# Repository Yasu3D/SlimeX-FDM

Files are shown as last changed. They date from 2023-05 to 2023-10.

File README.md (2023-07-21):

### !! This case was designed for specific parts, check [Guides](/README.md#-guides) for more info. !!
 
 It *may* fit other parts, but those setups are neither tested nor supported.

# 🦈 SlimeX-FDM
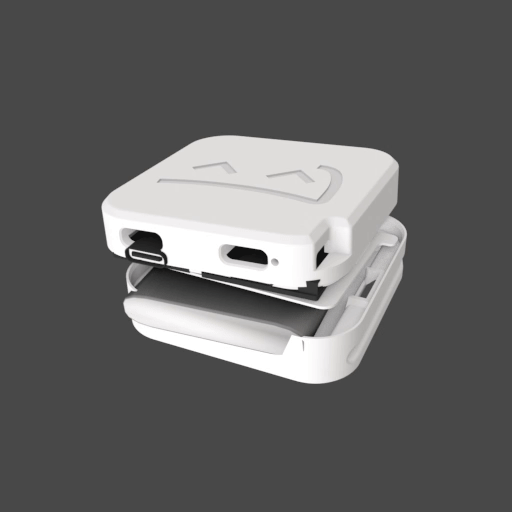
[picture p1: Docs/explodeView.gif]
woa cool animation

> woa cool animation

An easy to print, clean and very compact case design for SlimeVR.
Based on GniloAloe's SlimeX case, which is based on StonX.

Gniloe's design was intended for SLA printers. SlimeX-FDM is an adjusted version designed to be easier to print on FDM machines.

# ⚠️ Battery Safety Warning
- ***ALWAYS** separate the battery from the circuit boards to protect the battery from being poked by solder joints. Use a piece of craft foam or the provided 3d-printable battery-protector plastic card.*

- *Don't use V1 if you have battery tolerance issues!*

- *This case design is a **very** tight fit and may put a considerable amount of pressure on the battery if assembled incorrectly.*

- *Always ensure that your battery is safe and not a bomb please. I do not want to be held accountable for exploding trackers.*

# 📄 Changelog
| Version | Changes |
| - | - |
| V1 | Base Design |
| V2 | More space for battery, slightly larger I2C port |
| V3 | Complete remodel in Fusion360, .step file now available |
| V3.1 | Improved the clips, cases should stay together better now. |
| V3.2 | Fixed switch tolerances and made version text more readable. |
| V3.3 | Fixed case proportions on top and bottom, changed walls internally to get rid of gaps, changed i2c area to not destroy ports on insertion of wemos into slot, moved wemos pegs up for clearance, Inbuilt supports for top and buttom minus strap area, added indicator versions. |

# 📝 Guides
Always refer to the [SlimeVR Docs](https://docs.slimevr.dev/index.html) for the most up-to-date information. If you have any questions, ask in the [SlimeVR Discord](https://discord.gg/SlimeVR), DM me on Discord [Yasu#4645] or send me an [E-Mail](mailto:contact@yasu3d.art)

## Parts
SlimeX-FDM was designed around these parts. Resistors and Diodes obviously fit as well.
 - Wemos D1 Mini V4 Wifi Board // [Aliexpress](https://www.aliexpress.com/item/1005004605967379.html)
 - TP4056 USB-C Charger Board// [Aliexpress](https://www.aliexpress.com/item/1005004427739715.html)
 - SS22F32 Switch // [Aliexpress](https://www.aliexpress.com/item/1005003660190950.html)
 - BMI160 IMUs // [Aliexpress](https://www.aliexpress.com/item/4000084874141.html)
 - 804040 Li-Po Batteries // [Aliexpress](https://www.aliexpress.com/item/4000036291424.html)
 - 28AWG stranded silicone wire
 - [JST 1mm 4-pin / JST SH 4-pin connectors](https://jst.de/product-family/show/65/sh) for auxillary trackers // [Aliexpress](https://www.aliexpress.com/item/1005004350939786.html)

> please note that the Aliexpress pages are only for reference. It's recommended to look for other offers yourself.

> if any page is unavailable, the part name should be enough to find them.

> 1mm JST connector cables rarely come in lengths longer than 15cm. The linked page offers up to 30cm.

## 3D Printing
### Config
***TL;DR** 0.4mm nozzle, 0.15mm layers, 15% gyroid infill, arachne.*
***Can also print at .2 layer height, .2 initial layer height.*

Full config (that's been successful for me) can be found [here.](/Docs/SLICERCONFIG.md)

### Orientation/Arrangement
All STL files are exported in their correct orientation. The hollow inside of each case piece should point up:
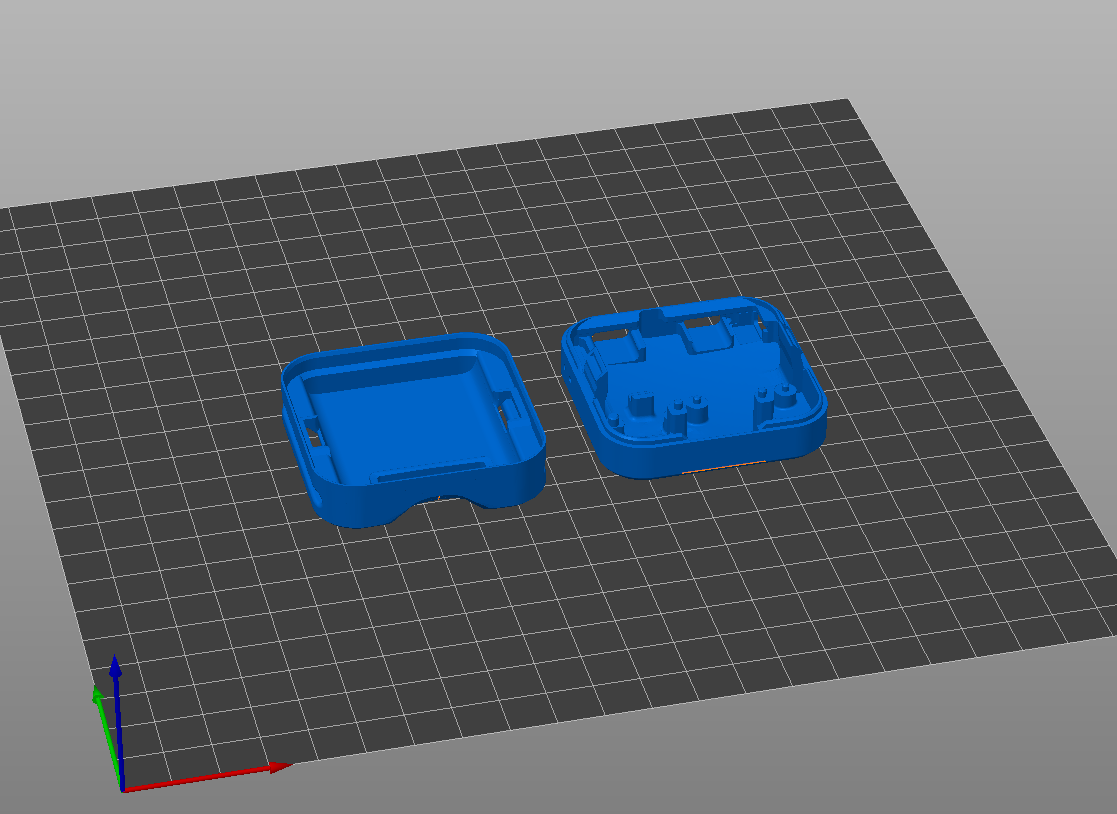
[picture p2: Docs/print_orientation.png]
print orientation

> This allows the case to be printed with minimal supports.

### Supports
If possible, use support-painting and organic supports with a slicer like PrusaSlicer 2.6.0.
This makes support material less wasteful and makes removing supports an absolute breeze.

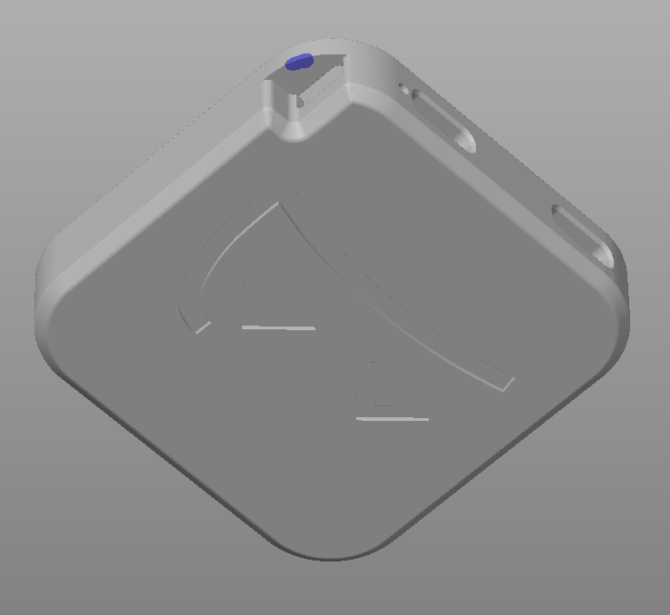
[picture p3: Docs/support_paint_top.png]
supports1

> supports under the I2C interface for auxillary trackers

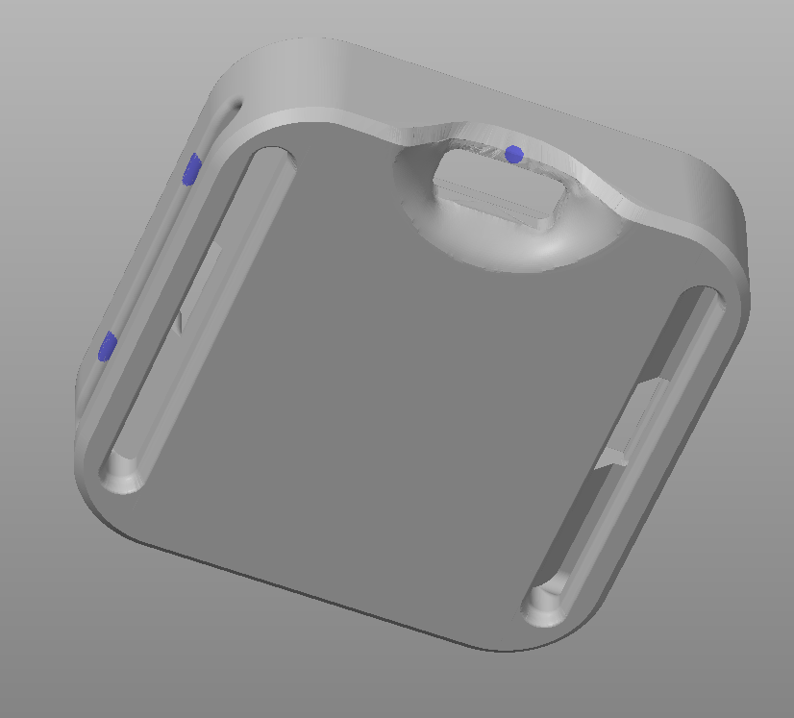
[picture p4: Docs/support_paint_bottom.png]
supports2

> supports for bridges around strap slots + support for bridge around switch.

> support painting on bottom shell is symmetrical.

## Soldering
//TBD, check smeltieVR's guide "Soldering for dummies" to learn the basics.

## Assembly
### Closing an empty case
- Line up pegs with switch slot
- Hook one clip into a slot
- Push halves together, slowly increasing pressure until it snaps shut.

its as shrimple as that

### Assembling a full tracker (refer to animation for visual guide)
**Battery:** (bottom case)
- Place battery in bottom case. May require a little pushing to move the circuit board at the top of the battery. That's fine.
- Route the battery cable in a way that it pokes out on the right side of the switch slot.

**Boards:** (top case)
- Place the BMI160 in the top right corner, make sure that it is laying flat or as flat as possible. Bend wiring if necessary.
- Push TP4056 and Wemos D1 Mini into the bottom half of the case. They're a very tight fit and assembly might be tricky because of the clips, wiring and pegs. Patience and some pressure is key to get them in their spot.
- Make sure the TP4056 lies flat and that the USB-C port is almost flush with the port on the case. If necessary, bend some wiring.
- Make sure the D1 Mini's I2C interface lines up with the port on the case. (the small cutout on one of the corners)
> - The D1 Mini's USB-C port does not poke out as much as the TP4056. That's normal, you'll still be able to access it.
> - The D1 Mini's I2C interface should line up, even if the tracker won't be used with an auxillary tracker. That's because the USB-C port may be too far in to properly access and because the pegs the D1 Mini sits on may not align.
> - It sometimes takes a considerable amount of force to get the D1 Mini in place. It feels a little scary, but it's normal.

**Switch:**
- Place the switch on the pegs, not in the slot. This is to ensure alignment when closing the case.
- If your wiring is too long the switch may become temperamental and will jump off the pegs. Press it down and optionally tape it to show it who's boss and put it in it's place.

**Closing:**
- Same process as an empty case, but this time you have to do it with a bunch of components in the way.
- Make sure nothing's poking the battery
- Make sure nothing's in the way of the switch and clips.
- Conglaturations! You did it :3

[May your trackers be many and your drifters few.](https://www.youtube.com/watch?v=CgHS1fa69aU)

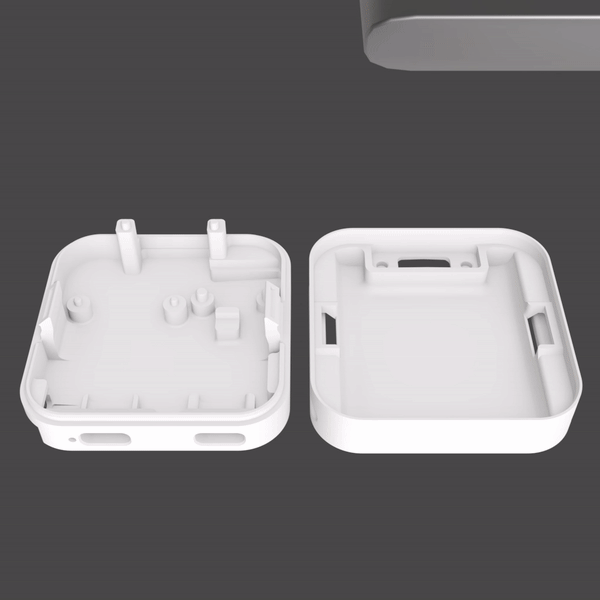
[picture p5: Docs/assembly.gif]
woo other cool animation


## Disassembly
If you need to troubleshoot or maintain your trackers, they're easily opened with the flat end of tweezers or a butter knife. Be slow to ensure you don't break anything.
- Hold case gentle like hamster
- Gently push against one of the clips inside the strap slots
- Apply a little force upwards with your fingers until case pops free.
 
Mind the cables and battery. You can carefully open the tracker like a book along the top edge (where the switch is).

disassembly IRL

## Durability
Standard PLA(+) is recommended. ***Don't use silk PLA.***
If your filament is brittle, the clips *may* break. 

I durability-tested with silk and non-silk PLA+ and the clips on silk cases snapped with minor force applied. I couldn't even break a non-silk clip so far. (I've tried about 5 times with all my strength. It just doesn't want to break.)

If you repeatedly open and close a case (20+ times), you ***will*** shave off the small hooks that make the clips work properly. Once worn down, the case will still stay together but can easily be opened by pulling the two halves apart. This may be fixed in a design revision, but it's hard to find a balance between ease of use and durability for the clips. Just press against the clips and open them slowly, then you'll be ok.

I've also stood on top of a case (~85kg) and it didn't even buckle much lol. You'll be fine laying on one if your bed isn't made of concrete.

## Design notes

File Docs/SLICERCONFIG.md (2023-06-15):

## [Back to README.md](/)

# 🖨️ My printer
- Stock Voron 2.4r2 350mm (current)
  - E3D v6 w/ 0.4mm nozzle

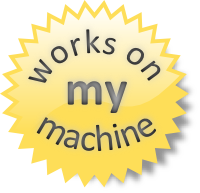
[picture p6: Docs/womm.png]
works on my machine


# ⚙️ My config - using Prusaslicer 2.6.0-rc1

## Print
Anything not mentioned is either irrelevant or probably standard.
These settings are for my Voron 2.4

### Layers and Perimeters
| Parameter | Value |
| - | - |
| Layer height | 0.15mm |
| First layer height | 0.2mm |
| Perimeters | 3 |
| Solid top layers | 6 |
| Solid bottom layers | 5 |
| Thick bridges | ☑ |
| Detect bridging perimeters | ☑ |
| Fill gaps | ☑ |
| Perimeter generator | Arachne |

### Infill, Skirts and Supports

| Parameter | Value |
| - | - |
| Fill density | 15% |
| Fill pattern | Gyroid or Cubic |
|  |  |
| Skirt loops | 3 (maybe overkill and irrelevant to the print) |
|  |  |
| Support style | Organic |
| Top contact Z  | 0.15mm |
| Bottom contact Z | 0.15mm |
| Interface layers | 1 |

### Speeds
This is very printer-dependent. Don't blindly copy this.

| Parameter | Value |
| - | - |
| Perimeters | 100mm/s |
| Small perimeters | 40mm/s |
| External perimeters | 40mm/s |
| Infill | 125mm/s |
| Solid infill | 120mm/s |
| Top solid infill | 50mm/s |
| Supports | 90mm/s |
| Support interface | 70mm/s |
| Bridges | 60mm/s |
| Gap fill | 40mm/s |
| First layer speed | 30mm/s |

## Filament

- Sunlu Marble PLA+

| Parameter | Value |
| - | - |
| Diameter | 1.75mm |
| Extrusion multiplier | 1 |
| Nozzle temp. | 205°C |
| Bed temp. | 60°C |

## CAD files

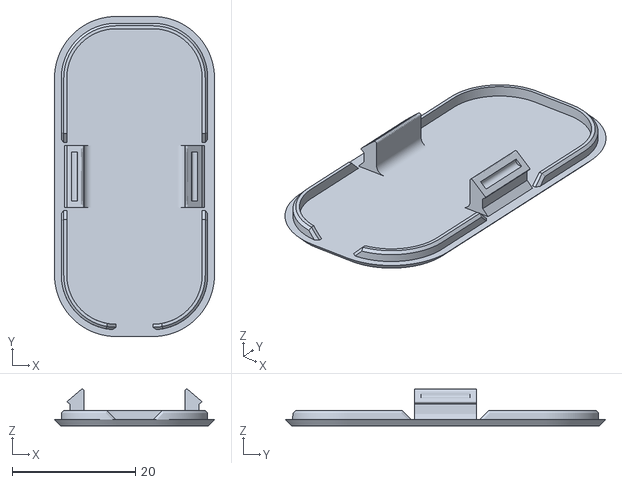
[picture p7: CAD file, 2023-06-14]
Case Files/AuxCases/V3.1/V3.1_SlimeX-FDM_Aux_Top.stl
26.0 x 52.0 x 5.97

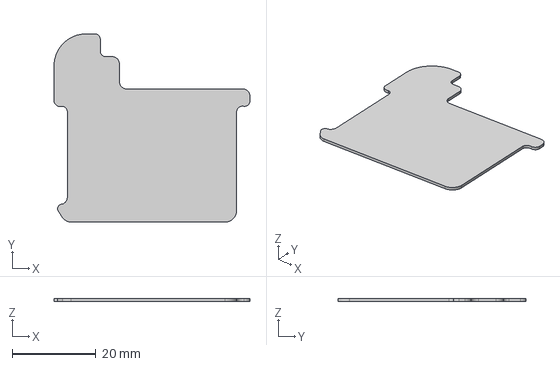
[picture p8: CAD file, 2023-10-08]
Case Files/MainCases/Battery Protector/Battery Protector.step
46.9 x 45.0 x 0.7 mm

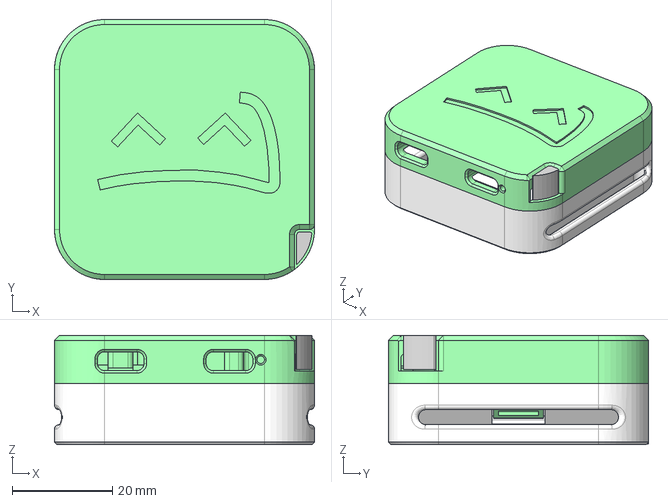
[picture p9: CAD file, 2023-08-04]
Case Files/MainCases/V3.3/Cad Files/V3.3_SlimeX-FDM.step
52.0 x 52.0 x 21.8 mm
SlimeX Top
SlimeX Bottom

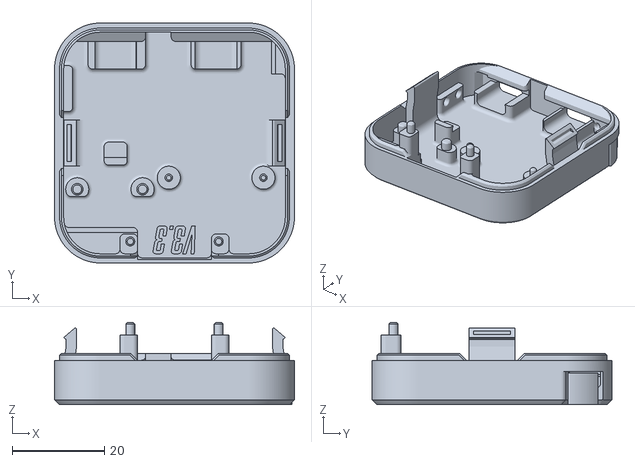
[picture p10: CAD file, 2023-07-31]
Case Files/MainCases/V3.3/Standard/SlimeX Top.stl
52.0 x 52.0 x 17.8

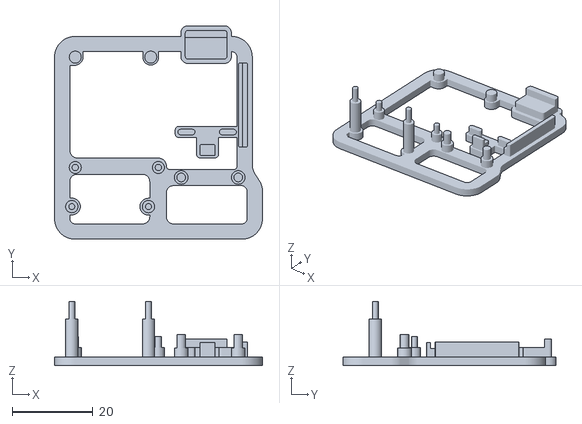
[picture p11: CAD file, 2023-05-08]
Case Files/SlimeX_SolderGuide_V3.stl
51.6 x 53.0 x 15.9

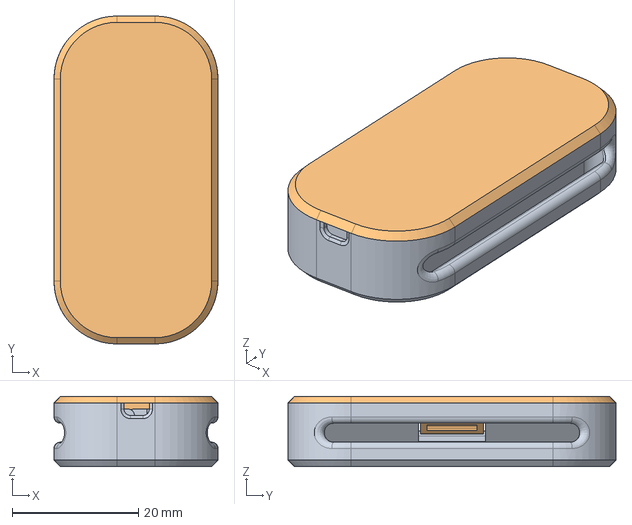
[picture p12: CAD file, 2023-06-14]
Case Files/AuxCases/V3.1/V3.1_SlimeX-FDM_Aux.step
26.0 x 52.0 x 11.1 mm
SlimeX Auxillary Bottom
SlimeX Aux Top

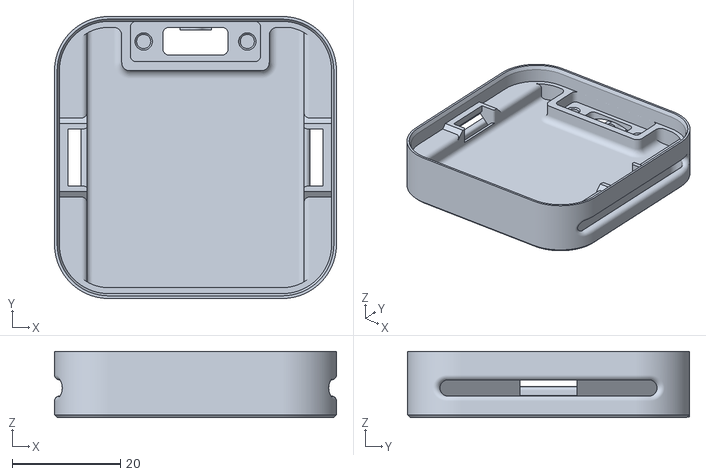
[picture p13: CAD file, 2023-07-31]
Case Files/MainCases/V3.3/Standard/SlimeX Bottom.stl
52.0 x 52.0 x 12.2

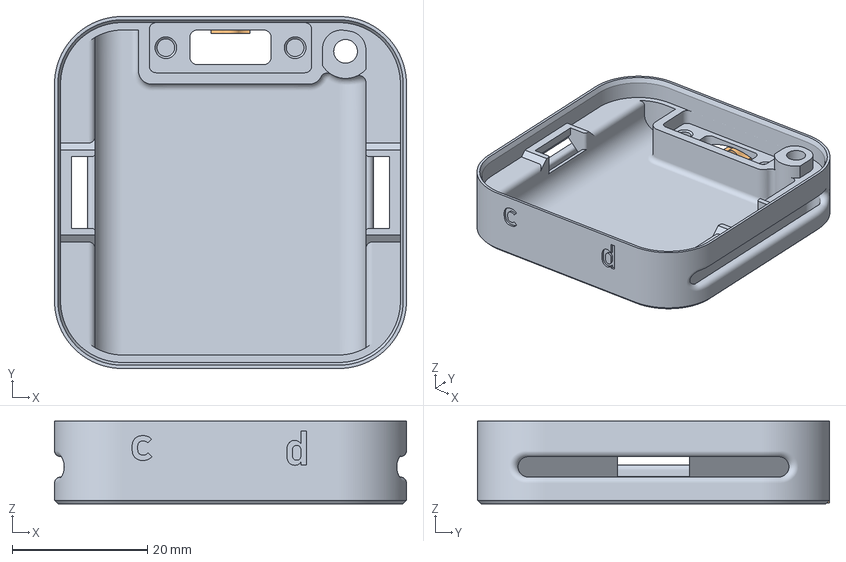
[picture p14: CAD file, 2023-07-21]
Case Files/MainCases/V3.3/With indicators/SlimeX Bottom with indicators.3mf
52.0 x 52.0 x 12.2 mm
Support

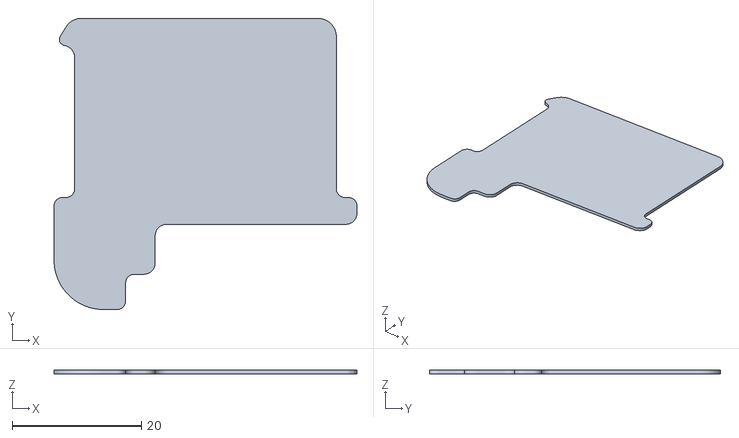
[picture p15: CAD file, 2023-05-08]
Case Files/SlimeX-FDM_BatteryProtector.stl
46.9 x 45.0 x 0.577

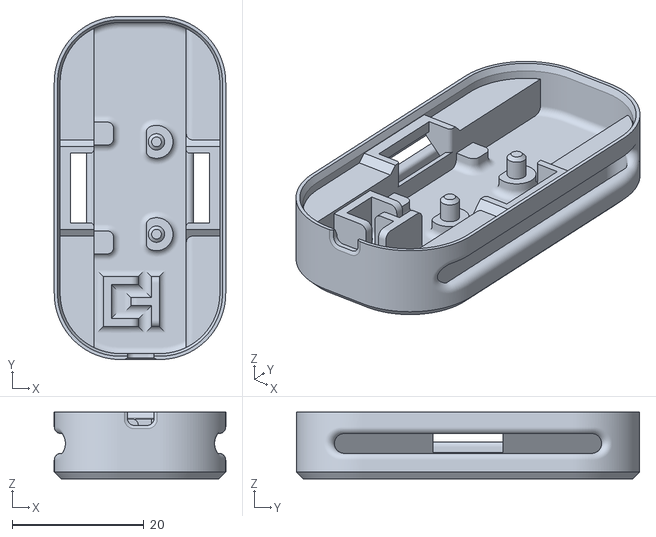
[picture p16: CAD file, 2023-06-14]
Case Files/AuxCases/V3.1/V3.1_SlimeX-FDM_Aux_Bottom.stl
26.0 x 52.0 x 10.1

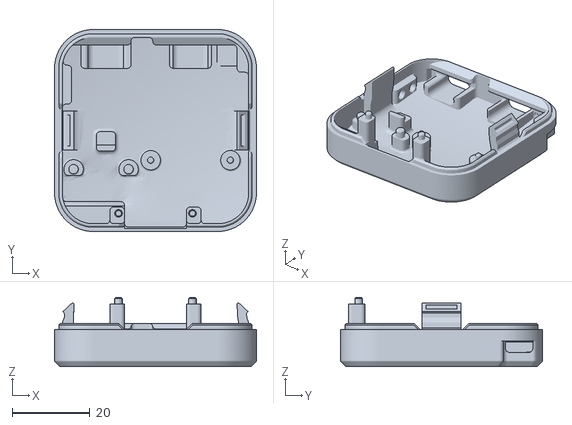
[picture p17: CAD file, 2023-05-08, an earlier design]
Case Files/MainCases/V1.0/SlimeX-FDM_Top.stl
52.0 x 52.0 x 17.8

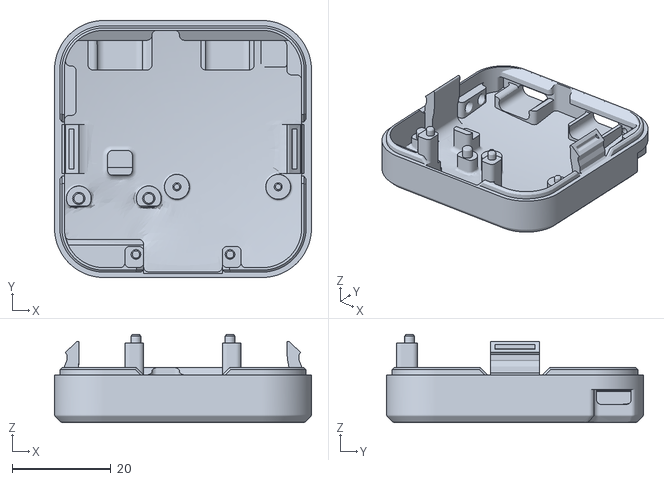
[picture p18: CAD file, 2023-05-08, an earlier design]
Case Files/MainCases/V1.0/SlimeX-FDM_Top_NoLogo.stl
52.0 x 52.0 x 17.8

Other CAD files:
Case Files/MainCases/V3.3/With indicators/SlimeX Top with indicators.3mf
Case Files/MainCases/V2.0/SlimeX-FDM_Bottom_V2.stl
Case Files/MainCases/V3.0/V3.0_SlimeX-FDM_Top_Logo.stl
Case Files/MainCases/V3.1/V3.1_SlimeX-FDM_Top_Logo.stl
Case Files/MainCases/V3.2/V3.2_SlimeX-FDM.step
Case Files/MainCases/V2.0/SlimeX-FDM_Top_V2.stl
Case Files/MainCases/V1.0/SlimeX-FDM_Bottom.stl
Case Files/MainCases/V2.0/SlimeX-FDM_Top_NoLogo_V2.stl
Case Files/MainCases/V3.0/V3.0_SlimeX-FDM.step
Case Files/MainCases/V3.0/V3.0_SlimeX-FDM_Bottom.stl
Case Files/MainCases/V3.0/V3.0_SlimeX-FDM_Top_NoLogo.stl
Case Files/MainCases/V3.1/V3.1_SlimeX-FDM.step
Case Files/MainCases/V3.1/V3.1_SlimeX-FDM_Bottom.stl
Case Files/MainCases/V3.1/V3.1_SlimeX-FDM_Top_NoLogo.stl
Case Files/MainCases/V3.2/V3.2_SlimeX-Bottom.stl
Case Files/MainCases/V3.2/V3.2_SlimeX-FDM_Top_Logo.stl
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

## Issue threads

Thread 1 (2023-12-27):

What is the license used?

Christmaswreath, 2023-12-27:

Yasu3D, 2023-12-27:
I haven't put proper thought into that / bothered writing my own license.

I suppose the best fitting license would be CC-BY-NC-SA.

TL;DR of what I'm expecting:
- Provide credit when sharing (link to this repository is fine)
- Only for Non-Commercial use, **unless you have my explicit permission**.
  - You cannot sell the 3d *model*.
  - You cannot sell 3d *prints*.
  - You cannot sell trackers made with this case.
- Any derivative works must follow this license as well.

It's also encouraged to contribute directly to this project and not create "new" versions of it. If you improve the design and want to share it, open a pull request.

Closed 2023-12-27.

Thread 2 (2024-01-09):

Compatibility with the community-made BMI270 and LSM6DSV gyros

barretgoat, 2024-01-09:
I want to preface this write-up by saying that it is not as much of an issue as it is an opportunity for improvement of the design.

A community member in the SlimeVR Discord server has started offering breakout boards carrying improved IMUs, the BMI270 and the LSM6DSV, both showing vastly improved performance over the BMI160 yet having exactly the same dimensions and overall footprint.

The only difference is that to simplify the trace routing, the author opted to remove the mounting holes, which renders SlimeX the only case that is currently unable to fit the new gyros on account of actually making use of the mounting holes in BMI160 boards.

The current cases still work if one were to break off the thin part of the mounting posts with pliers and then secure the IMU with some hotglue, but I suspect that the case file could just as easily be reworked to accomodate the community IMUs without breaking the compatibility with the BMI160.

The simplest way I can see is removing the part of the posts which actually goes in the hole on the board and ensuring that the support for the charging board is close enough to the IMU that it is held in place by friction alone, though I suspect there might be a smarter way to go about it.

Also, linking the Discord thread with the discussion of the new IMUs: https://discord.com/channels/817184208525983775/1176860516140978308

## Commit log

2023-05-08 push v1 case
    [SlimeX-FDM_BatteryProtector.stl, SlimeX-FDM_Bottom.stl, SlimeX-FDM_Top.stl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]
2023-05-21 uploaded new V2 case and reorganized things
    [SlimeX-FDM_BatteryProtector.stl, SlimeX-FDM_Bottom_V2.stl, SlimeX-FDM_Top_NoLogo_V2.stl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]
2023-05-24 fix scaling on V2 STLs
    [SlimeX-FDM_Bottom_V2.stl, SlimeX-FDM_Top_NoLogo_V2.stl, SlimeX-FDM_Top_V2.stl]
2023-05-25 restructuring and v3.0 release
    [SlimeX-FDM_BatteryProtector.stl, SlimeX-FDM_Bottom.stl, SlimeX-FDM_Bottom_V2.stl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]
2023-05-25 flipped cases
    [V3.0_SlimeX-FDM_Top_Logo.stl, V3.0_SlimeX-FDM_Top_NoLogo.stl]
2023-05-25 update to v3.1 for better clips
    [V3.1_SlimeX-FDM.step, V3.1_SlimeX-FDM_Bottom.stl, V3.1_SlimeX-FDM_Top_Logo.stl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]
2023-05-25 fix dumb mistake thats not worth a version number
    [V3.1_SlimeX-FDM_Top_Logo.stl, V3.1_SlimeX-FDM_Top_NoLogo.stl]
2023-05-26 another fix because I'm stupid
    didn't mirror an operation and messed up the case clip mechanism
    [V3.1_SlimeX-FDM.step, V3.1_SlimeX-FDM_Bottom.stl]
2023-05-26 slight tweak to tp4056 usbc port
    [V3.1_SlimeX-FDM_Top_Logo.stl, V3.1_SlimeX-FDM_Top_NoLogo.stl]
2023-06-14 aux case release
    [V3.1_SlimeX-FDM_Aux.step, V3.1_SlimeX-FDM_Aux_Bottom.stl, V3.1_SlimeX-FDM_Aux_Top.stl]
2023-06-15 v3.2 release - repository reorganized
    [SlimeX-FDM_Bottom.stl, SlimeX-FDM_Bottom_V2.stl, SlimeX-FDM_Top.stl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]
2023-07-21 Version 3.3 upload
    This version is a major revision to 3.2. Changed alot of things to make the design more elegant and practical. also added hole/indicator versions.
    [SlimeX Bottom with indicators.3mf, SlimeX Bottom with indicators.stl, SlimeX Bottom.3mf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]
2023-07-21 Update orientation of v3 top stls
    Tops were not oriented correctly.
    [SlimeX Top with indicators.stl, SlimeX Top.stl]
2023-07-31 Changes to v3.3 to fix charge board
    Moved chargeboard forward slightly, fixed battery wobble.
    [SlimeX Bottom with indicators.stl, SlimeX Bottom.3mf, SlimeX Bottom.stl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]
2023-08-04 Initial upload of v3.3 step files
    Upload of cad files for 3.3
    [V3.3_SlimeX-FDM.step]
2023-10-08 Create Battery Protector.step
    initial commit for battery protector step file
    [Battery Protector.step]
